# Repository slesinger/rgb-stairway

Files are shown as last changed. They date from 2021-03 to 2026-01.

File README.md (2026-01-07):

# 🌈 RGB Stairway Lighting

> Transform your staircase into a dynamic light show with motion detection and Home Assistant integration

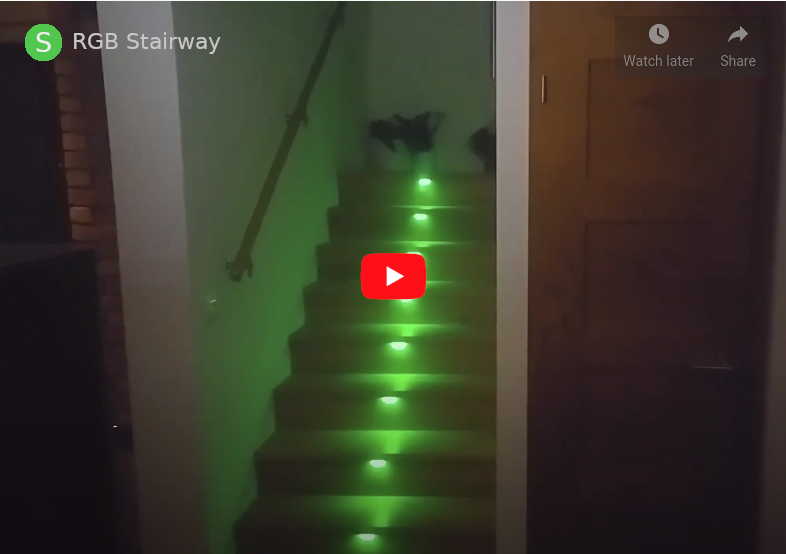
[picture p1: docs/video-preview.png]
Video Demo (https://www.youtube.com/watch?v=-Y23b8RhR6I)


## ✨ What Is This?

An ESP32-powered smart stairway lighting system that makes every trip up or down the stairs a delightful experience. Using WS2812B LED strips and IR motion detection, your stairs automatically illuminate with customizable color animations when someone approaches—then gracefully fade away. Effects can be tailored via MQTT commands from Home Assistant, allowing for endless creativity.

**Why you'll love it:**
- 🎯 Automatic detection via IR sensors (no false triggers!)
- 🎨 Per-step color control with smooth blending
- 🏠 Full Home Assistant integration via MQTT
- 🌙 Day/Night modes for smart automation
- 🎭 Custom animation programs (or use built-in random colors)
- ⚡ Real-time response using ESP32 dual-core processing
- 🔧 Easy WiFi setup with captive portal

**Creative ideas to try:**
- 🎆 National colors on holidays
- 📬 Light up N steps to show unread emails
- 🔔 Flash all stairs when someone rings the doorbell
- 🏓 Ping-pong game (race the light wave!)
- 🏃 Kids competing to beat the animation
- 🎨 Daily color themes synced with your smart home

## 🛠️ Hardware Requirements

### Components
- **ESP32** development board (e.g., Lolin32) - ESP8266 won't cut it, we need dual cores!
- **WS2812B LED strips** - 3 LEDs per step (48 LEDs total for 16 steps)
- **2× IR LED transmitters** (38kHz compatible)
- **2× IR receivers/phototransistors**
- **Quality wiring** - Use UTP cable pairs (16 wires total) for reliability
- **Power supply** - 5V, sized for your LED count

### Tested Configuration
- 16 steps total (8 bottom + 8 top)
- 3 LEDs per step
- Split into two separate strips to avoid voltage drop

> ⚠️ **Important:** Don't power more than 8 steps from one end. Split your LED strips into upper and lower sections!

## 🔌 Wiring Guide

### ESP32 Pin Assignments

| Pin | Function | Description |
|-----|---|---|
| **GPIO 13** | Bottom LED Data | WS2812B data line (steps 0-7) |
| **GPIO 12** | Top LED Data | WS2812B data line (steps 8-15) |
| **GPIO 4** | Bottom IR Receiver | IR sensor input (first step) |
| **GPIO 17** | Top IR Receiver | IR sensor input (last step) |
| **GPIO 16** | Top IR Transmitter | IR LED output (36kHz carrier) |

### Connection Notes
- Power both LED strips from adequate 5V supply
- ESP32 and LEDs should share common ground
- IR sensors work best with ~1-2 meter range across the step
- Consider resistors for IR LEDs (typically 100-330Ω depending on your LEDs)

## 🏠 Home Assistant Integration

### MQTT Topics

#### Published by Device
| Topic | Values | Description |
|---|---|---|
| `schody/sviti` | `on` / `off` | Whether any animation is currently running |
| `schody/status` | `noc` / `den` / `RECONNECTED` | Night/day mode status or reconnection event |
| `schody/ir/dole` | `on` / `off` | Bottom step IR beam broken |
| `schody/ir/nahore` | `on` / `off` | Top step IR beam broken |

#### Subscribed by Device
| Topic | Payload | Description |
|---|---|---|
| `schody/cmd` | Animation program | Custom color animation sequence |
| `schody/mode` | `N` / `D` / `R` | Night mode / Day mode / Reset |
| `schody/status` | Any | Acknowledged (resets watchdog) |

### Day/Night Modes

**Night Mode (`N`):**
- IR sensors trigger built-in animations (`PROGRAM_UPSTAIRS`/`PROGRAM_DOWNSTAIRS`)
- Instant response (~0ms delay)
- Perfect for automatic operation

**Day Mode (`D`):**
- IR sensors only publish MQTT events
- No automatic animations
- Great for manual control or disabling lights during daytime

### Sending Programs from Home Assistant

#### Simple Example (Single Step Test)
```yaml
# In your automation or script
service: mqtt.publish
data:
  topic: "schody/cmd"
  payload: "0:100(120r0g0b)1000(0r0g120b)100(0r0g0b)"
```

#### Wave Effect (All Steps)
```yaml
service: mqtt.publish
data:
  topic: "schody/cmd"
  payload: >
    0:10(0r0g0b)100(0r120g0b)8000(254r254g254b)2000(0r0g0b)
    1:50(0r0g0b)100(0r120g0b)8000(254r254g254b)2000(0r0g0b)
    2:100(0r0g0b)100(0r120g0b)8000(254r254g254b)2000(0r0g0b)
    3:150(0r0g0b)100(0r120g0b)8000(254r254g254b)2000(0r0g0b)
    ...
```

#### Random Color Animation
```yaml
service: mqtt.publish
data:
  topic: "schody/cmd"
  payload: >
    0:10(0r0g0b)100(255r255g255b)8000(254r254g254b)2000(0r0g0b)
    1:50(0r0g0b)100(255r255g255b)8000(254r254g254b)2000(0r0g0b)
    ...
```

### Program Syntax

**Format:** `<step>:<period>(<r>r<g>g<b>b)<period>(<r>r<g>g<b>b)...`

- **step:** Step number (0-15)
- **period:** Duration in **3ms ticks** (100 = 300ms)
- **r/g/b:** Color intensity (0-127 for normal values)

**Special Color Values:**
- `254` - Copy that channel from previous animation step's target (per-channel persistence)
- `255` - Random hue (generates one random color at 50% brightness)

**Examples:**
```
# Fade to red, hold, fade to black
0:10(0r0g0b)100(60r0g0b)1000(254r254g254b)2000(0r0g0b)

# Fade to red, shift to purple (R maintained, add blue)
0:10(0r0g0b)100(60r0g0b)1000(254r254g40b)2000(0r0g0b)

# Random color, hold, fade out
0:10(0r0g0b)100(255r255g255b)8000(254r254g254b)2000(0r0g0b)
```

### Home Assistant Configuration Example

```yaml
# configuration.yaml
mqtt:
  broker: YOUR_BROKER_IP
  port: 8883
  username: !secret mqtt_user
  password: !secret mqtt_password

# automations.yaml
- alias: "Stairs: Night Mode at Sunset"
  trigger:
    - platform: sun
      event: sunset
  action:
    - service: mqtt.publish
      data:
        topic: "schody/mode"
        payload: "N"

- alias: "Stairs: Day Mode at Sunrise"
  trigger:
    - platform: sun
      event: sunrise
  action:
    - service: mqtt.publish
      data:
        topic: "schody/mode"
        payload: "D"

- alias: "Stairs: Demo Animation"
  trigger:
    - platform: state
      entity_id: input_button.stairs_demo
      to: "on"
  action:
    - service: mqtt.publish
      data:
        topic: "schody/cmd"
        payload: >
          0:50(0r0g0b)60(0r120g0b)85(0b120g0r)60(0r0g0b)
          1:200(0r0g0b)60(0r120g0b)85(0b120g0r)60(0r0g0b)
          2:300(0r0g0b)60(0r120g0b)85(0b120g0r)60(0r0g0b)
          3:450(0r0g0b)60(0r120g0b)85(0b120g0r)60(0r0g0b)
```

## 📦 Installation

### Prerequisites
- [PlatformIO](https://platformio.org/) installed
- Python 3.x
- Git

### Quick Start

1. **Clone the repository**
   ```bash
   git clone https://github.com/slesinger/rgb-stairway.git
   cd rgb-stairway
   ```

2. **Create your config file**
   ```bash
   cp src/config.h-template src/config.h
   nano src/config.h  # Edit with your settings
   ```

3. **Configure settings in `src/config.h`**
   ```cpp
   #define MQTT_HOST  "192.168.1.2"      // Your MQTT broker IP
   #define MQTT_PORT  8883                // MQTT port
   #define MQTT_USER  "hass"              // MQTT username
   #define MQTT_PASS  "your_password"     // MQTT password
   
   #define WIFI_SETUP_AP_NAME "stupnice"  // Initial WiFi AP name
   #define WIFI_SETUP_AP_PASS "password123" // Initial WiFi AP password
   ```

4. **Build and upload**
   ```bash
   pio run --target upload
   ```

5. **Monitor serial output (optional)**
   ```bash
   pio device monitor
   ```

### First-Time WiFi Setup

On first boot (or when WiFi credentials are lost):

1. ESP32 creates WiFi access point named `stupnice` (or your configured name)
2. Connect to it with password `password123` (or your configured password)
3. Captive portal opens automatically (or navigate to `192.168.4.1`)
4. Select your WiFi network and enter password
5. Device reboots and connects to your network

The device will remember credentials and auto-reconnect on subsequent boots.

### Testing Your Installation

Send a test MQTT message:
```bash
mosquitto_pub -h YOUR_BROKER -p 8883 -u hass -P password \
  -t schody/cmd \
  -m "0:100(120r0g0b)1000(0r120g0b)100(0r0g0b)"
```

## 🧰 Maintenance & Updates

**Update PlatformIO packages:**
```bash
pio pkg update
```

**View serial logs:**
```bash
pio device monitor
```

**Clean build:**
```bash
pio run --target clean
pio run --target upload
```

## 📚 Libraries Used

This project leverages these excellent libraries:

- **[NeoPixelBus](https://github.com/Makuna/NeoPixelBus)** (v2.7.9+) - WS2812B LED control with DMA
- **[WiFiManager](https://github.com/tzapu/WiFiManager)** - Easy WiFi configuration
- **[PubSubClient](https://github.com/knolleary/pubsubclient)** (v2.8.0+) - MQTT client
- **[ArduinoOTA](https://github.com/esp8266/Arduino)** - Over-the-air updates (commented out by default)
- **ESP32 Arduino Core** - FreeRTOS and hardware abstraction

## 🔧 Advanced Configuration

### Customizing Default Animations

Edit `src/config.h` to modify built-in animations:

```cpp
// Random colors ascending
#define PROGRAM_UPSTAIRS "0:10(0r0g0b)100(255r255g255b)8000(254r254g254b)2000(0r0g0b) ..."

// Random colors descending
#define PROGRAM_DOWNSTAIRS "15:10(0r0g0b)100(255r255g255b)8000(254r254g254b)2000(0r0g0b) ..."

// Boot animation
#define PROGRAM_INIT "0:100(120r0g0b)100(0r120g0b)100(0r0g120b)1000(0r0g120b)100(0r0g0b)..."
```

### Adjusting Hardware Pins

Modify in `src/config.h`:
```cpp
#define NUM_SCHODU 16           // Total number of steps
#define STRIP_DOLE_PIN 13       // Bottom strip data pin
#define STRIP_NAHORE_PIN 12     // Top strip data pin
#define IR_RECV_DOLE_PIN 4      // Bottom IR receiver
#define IR_RECV_NAHORE_PIN 17   // Top IR receiver
#define IR_LED_NAHORE_PIN GPIO_NUM_16  // IR transmitter
```

## 🐛 Troubleshooting

**LEDs not lighting:**
- Check 5V power supply is adequate
- Verify data pin connections
- Ensure common ground between ESP32 and LED strips

**IR sensors not triggering:**
- Verify IR LED is powered and blinking (use phone camera to see IR)
- Check IR receiver orientation and range (1-2m optimal)
- Monitor serial output for IR debug messages

**WiFi connection issues:**
- Reset WiFi: Delete credentials and restart (access point will appear)
- Check WiFi signal strength
- Verify router supports 2.4GHz (ESP32 doesn't support 5GHz)

**MQTT not connecting:**
- Verify broker IP, port, username, password in `config.h`
- Check network connectivity: `ping YOUR_BROKER_IP`
- Monitor serial output for connection status
- Device auto-restarts if no status acknowledgment for 5 minutes

## 📄 License

This project is licensed under the MIT License - see the [LICENSE](LICENSE) file for details.

## 🙏 Contributing

Contributions are welcome! Feel free to:
- Report bugs
- Suggest new features
- Submit pull requests
- Share your stairway setup photos/videos

## ⭐ Show Your Support

If you like this project, give it a ⭐ on GitHub and share your installation on social media!

---

Made with ❤️ for makers who want their stairs to be awesome

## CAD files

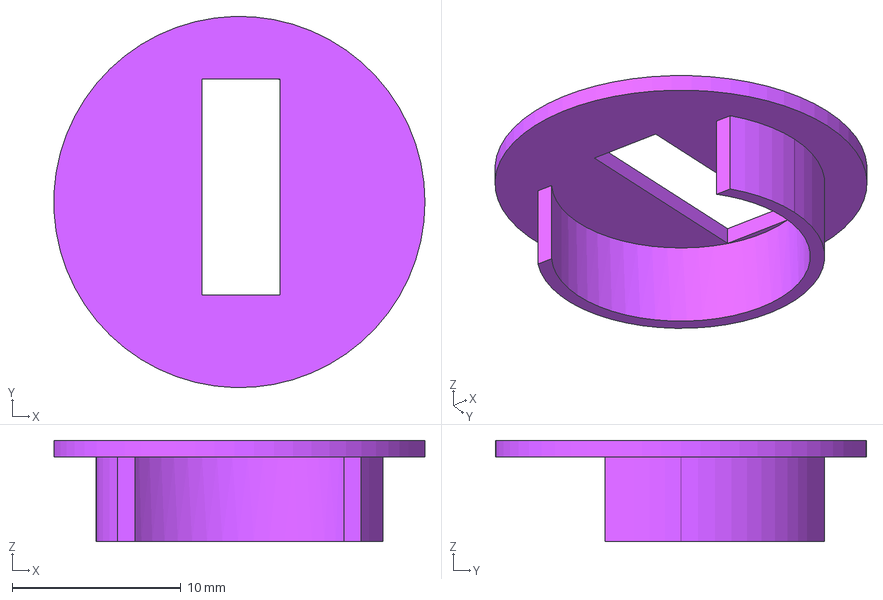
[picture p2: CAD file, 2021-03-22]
3dprint/ir-schody_v2.FCStd
22.0 x 22.0 x 6.00 mm

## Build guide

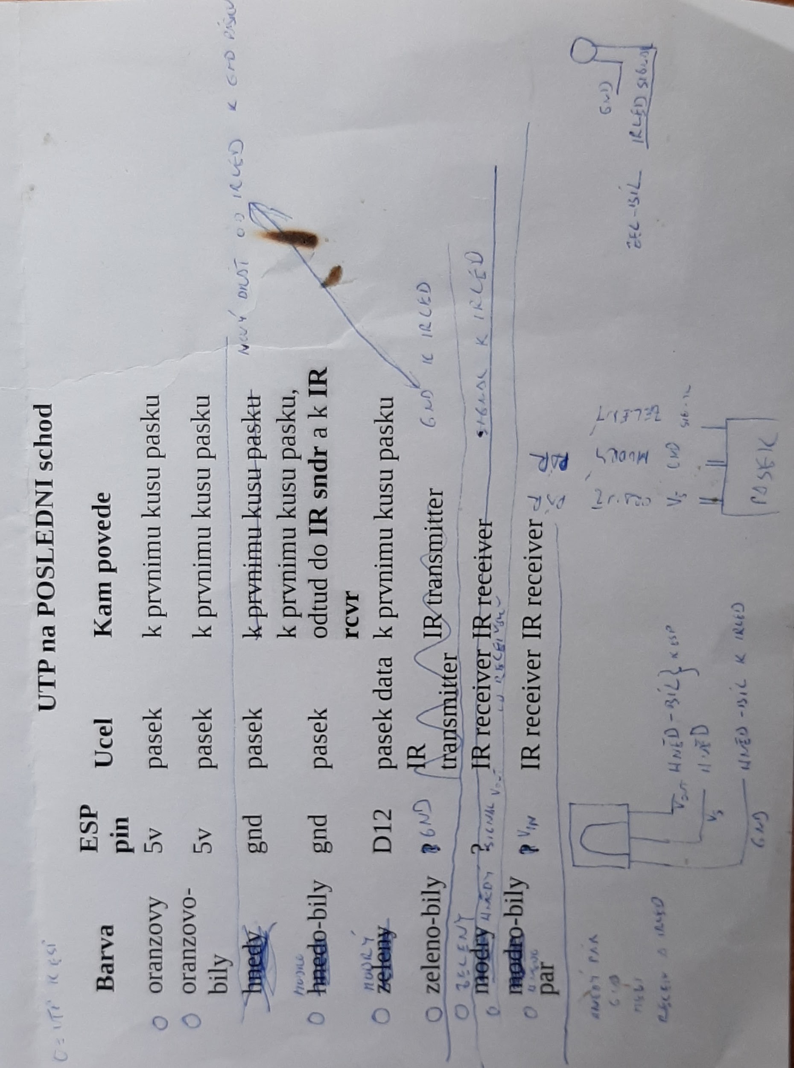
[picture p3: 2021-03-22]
docs/backup-wiring-2.jpg

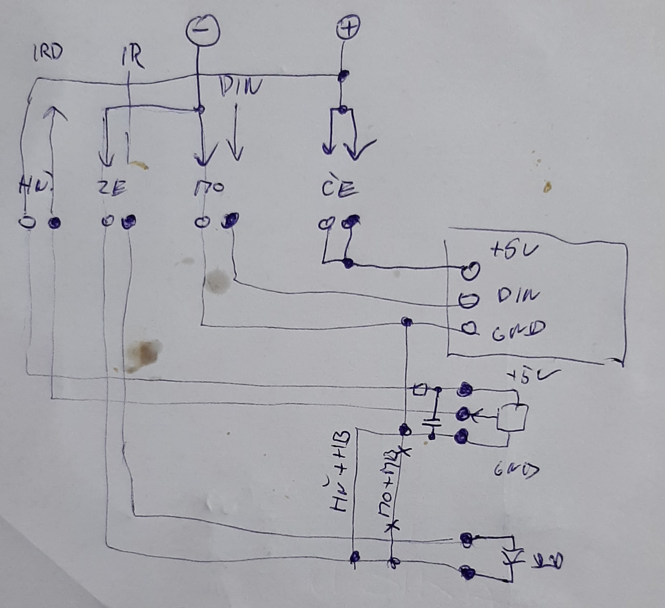
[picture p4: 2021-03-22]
docs/wiring-diagram.jpg

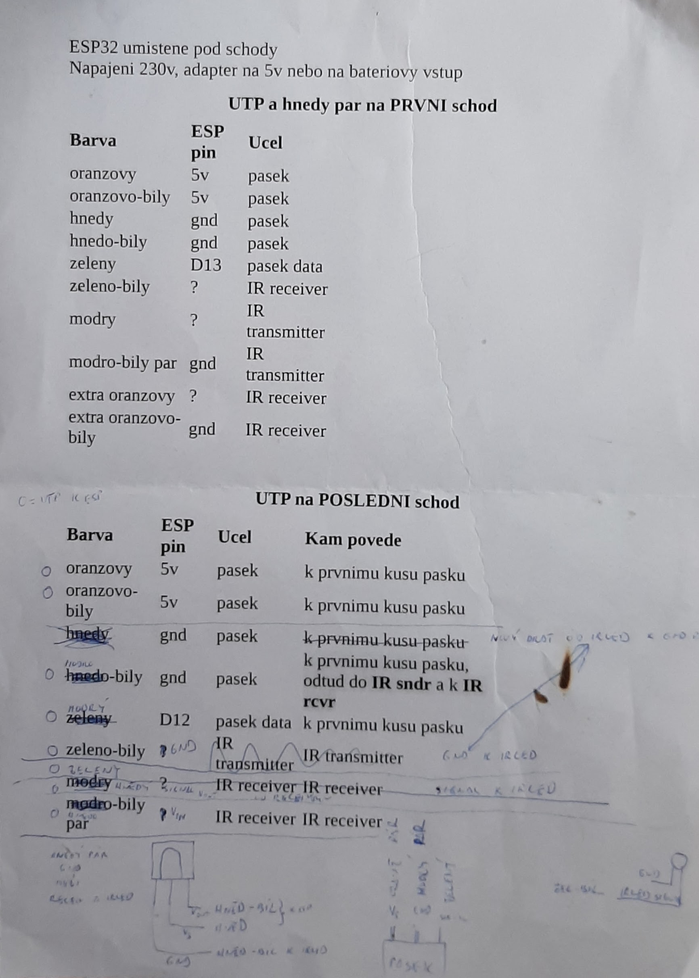
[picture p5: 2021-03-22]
docs/backup-wiring-1.jpg

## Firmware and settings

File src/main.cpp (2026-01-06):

/*
To test Schody, just publish message over MQTT:
mosquitto_pub -h localhost -p 8883 -u hass -P <mqtt password> -t schody/cmd -m <see below>

0:10(120r0g0b)1000(124R125g125B)1000(120r0g0b)1000(0r120g0b)1000(0r0g120b)1000(0r0g0b)
1:10(120r0g0b)1000(124R125g125B)1000(120g0r0b)1000(0r120b0g)1000(0b0g120r)1000(0r0g0b)

Program Syntax:
  <stair>:<period>(<r>r<g>g<b>b)<period>(<r>r<g>g<b>b)...
  
  - stair: Step number (0-15)
  - period: Duration in ticks (1 tick = 3ms)
  - r, g, b: Color values (case-insensitive)
  
  Color Value Special Cases:
    0-127: Normal color intensity
    254: Copy that specific channel from previous step's target (per-channel)
    255: Random color (single hue 0-255, saturation 100%, value 50%)
  
  Example: 0:10(0r0g0b)100(60r0g0b)1000(254r254g254b)2000(0r0g0b)
    - Fade to red, hold red for 1000 ticks (all channels copied), fade to black
  Example: 0:10(0r0g0b)100(60r0g0b)1000(254r254g40b)2000(0r0g0b)
    - Fade to red, transition to purple (R=60 copied, G=0 copied, B=40 new), fade to black

1 period = 3ms (actual execution time in task_led_strip)

Stairs are split to two part upper part (nahore) and bottom part (dole) 
*/

#include "config.h"
#include <Arduino.h>

#include <NeoPixelBus.h>

//needed for library
#include <WiFiManager.h>  //https://github.com/tzapu/WiFiManager WiFi Configuration Magic

#include <PubSubClient.h> //https://pubsubclient.knolleary.net/api.html
#include "driver/rmt.h"
#include <ArduinoOTA.h>


// builtin LED
//#define LED_BUILTIN 5
//#define DEBUG_PIN 27

#define RMT_TX_CHANNEL RMT_CHANNEL_0


bool was_falling_dole = false;
bool was_falling_nahore = false;

// which effect to display for start
RgbColor barva(10, 220, 150);
RgbColor black(0);
RgbColor c_null(0);
RgbColor red(128,0,0);
RgbColor green(0,128,0);
RgbColor blue(0,0,128);

NeoPixelBus<NeoGrbFeature, NeoEsp32I2s0800KbpsMethod> strip_dole(NUM_SCHODU/2*3, STRIP_DOLE_PIN);
NeoPixelBus<NeoGrbFeature, NeoEsp32I2s1800KbpsMethod> strip_nahore(NUM_SCHODU/2*3, STRIP_NAHORE_PIN);

WiFiManager wifiManager;
WiFiClient espClient;
PubSubClient client(espClient);

boolean irdole_publish = false;
boolean irnahore_publish = false;
boolean ma_se_poslat_konec_sviceni = true;
boolean is_night_enabled = true;
long lastStatusAck = 0;

void setSchod(int id, RgbColor moje_barva)
{
  // moje_barva.Darken(255 - intenzita);
  if (id <= 7) {
    int i = id * 3;
    strip_dole.SetPixelColor(i, moje_barva);
    strip_dole.SetPixelColor(i+1, moje_barva);
    strip_dole.SetPixelColor(i+2, moje_barva);
  }
  else {
    int i = (15 - id) * 3;
    strip_nahore.SetPixelColor(i, moje_barva);
    strip_nahore.SetPixelColor(i+1, moje_barva);
    strip_nahore.SetPixelColor(i+2, moje_barva);
  }
}

void showSchody(){
  strip_dole.Show();
  strip_nahore.Show();
}

/* #Program
   for each stair-step
    commands:
      - //set_color (period, color) - same as blend(0, color)
      - blend (period, color) - as this is only command, does not need to specify in program, is implicit
    command parameter
      - period uint_16
      - target color
*/
struct RgbColorFloat {
  float R;
  float G;
  float B;
  float deltaR;
  float deltaG;
  float deltaB;
};
struct Program_step {
  uint16_t period;
  RgbColor target_color;
};
Program_step program[NUM_SCHODU][NUM_PROG_STEPS];
unsigned int program_pointers[NUM_SCHODU];
RgbColorFloat program_current_color[NUM_SCHODU];

void program_clear() {}

void program_load(byte* prg, unsigned int length) {
    // char prg[] = "0:1200(124R125g127B)0(0R0g0b)\n1:1201(121R121g121B)1(1R1g1b)";
    
    //init zero values
    for (int schod = 0; schod < NUM_SCHODU; schod++) {
      program_pointers[schod] = NUM_PROG_STEPS;   // pause execution
      program_current_color[schod] = {.R = 0, .G = 0, .B = 0, .deltaR = 0, .deltaG = 0, .deltaB = 0};

      for (int step = 0; step < NUM_PROG_STEPS; step++) {
        program[schod][step] = { .period = LAST_PROG_STEP, .target_color = black};
      }
    }

    //load from string
    unsigned int num = 0;
    unsigned int schod = 0;
    unsigned int step = 0;
    uint16_t period = 0;
    unsigned int r = 0;
    unsigned int g = 0;
    unsigned int b = 0;
    unsigned char* curr_prg = prg;
    for (unsigned int i = 0; i < length; i++) {
        unsigned char ch = *curr_prg;
        
        if (ch >= '0' && ch <= '9') {
            num = num*10 + ch-48;
        }
        if (ch == ':') {
            if (schod != num) step = 0;
            schod = num;
            num = 0;
        }
        if (ch == '(') {
            period = num;
            num = 0;
        }
        if (ch == 'R' || ch == 'r') {
            r = num;
            num = 0;
        }
        if (ch == 'G' || ch == 'g') {
            g = num;
            num = 0;
        }
        if (ch == 'B' || ch == 'b') {
            b = num;
            num = 0;
        }
        if (ch == ')') {
          if (schod < NUM_SCHODU && step < NUM_PROG_STEPS) {
            // Store values as-is, handling special values later
            uint16_t rr = (r >= 254) ? r : (r % 127);
            uint16_t gg = (g >= 254) ? g : (g % 127);
            uint16_t bb = (b >= 254) ? b : (b % 127);
            
            // Handle 254 per-channel: copy that specific channel from previous step's target
            if (step > 0) {
              RgbColor prev_target = program[schod][step - 1].target_color;
              if (rr == 254) rr = prev_target.R;
              if (gg == 254) gg = prev_target.G;
              if (bb == 254) bb = prev_target.B;
            } else {
              // For first step, if 254 is used, default to 0 for that channel
              if (rr == 254) rr = 0;
              if (gg == 254) gg = 0;
              if (bb == 254) bb = 0;
            }
            
            // Handle 255: generate random color using HSV
            // Generate single random hue (0-255), S=100%, V=50%
            if (rr == 255 || gg == 255 || bb == 255) {
              uint32_t random_val = esp_random();
              uint8_t hue = (random_val & 0xFF);  // Random hue 0-255
              
              // Create HSB color: Hue (0-360 mapped from 0-255), Saturation 100%, Brightness 50%
              // NeoPixelBus uses float values: H=0.0-1.0, S=0.0-1.0, B=0.0-1.0
              HsbColor hsb_color(hue / 255.0f, 1.0f, 0.5f);
              RgbColor rgb_color(hsb_color);
              
              // Only apply to channels that were set to 255
              if (rr == 255) rr = rgb_color.R;
              if (gg == 255) gg = rgb_color.G;
              if (bb == 255) bb = rgb_color.B;
            }
            
            program[schod][step] = { .period = period, .target_color = RgbColor(rr, gg, bb) };
            step++;
          } else {
            Serial.printf("Warning: Ignoring program step schod=%u, step=%u (out of bounds)\n", schod, step);
          }
        }
        curr_prg++;
    }

    for (int schod = 0; schod < NUM_SCHODU; schod++) {
      RgbColor targ_col = program[schod][0].target_color;
      // 254 values have already been resolved during parsing, so just use target as-is
      program_current_color[schod].deltaR = ((float)targ_col.R - 0) / (float)program[schod][0].period;
      program_current_color[schod].deltaG = ((float)targ_col.G - 0) / (float)program[schod][0].period;
      program_current_color[schod].deltaB = ((float)targ_col.B - 0) / (float)program[schod][0].period;
      program_pointers[schod] = 0;   // exceutes from 0 to NUM_PROG_STEPS
    }

  client.publish("schody/sviti", "on", true);
  ma_se_poslat_konec_sviceni = true;

}

void task_led_strip(void *parameter) {
  while (true) {

    //Execute program for each stair
    for (int schod = 0; schod < NUM_SCHODU; schod++) {

      if (program_pointers[schod] == NUM_PROG_STEPS) {
        continue; //program executed completely, skip this stair
      }

      if (program[schod][program_pointers[schod]].period == 0) {
        program_pointers[schod]++; //period for given step passed, go to next program step
        //calculate blending deltas (254 values already resolved during load)
        RgbColor targ_col = program[schod][program_pointers[schod]].target_color;
        program_current_color[schod].deltaR = ((float)targ_col.R - program_current_color[schod].R) / (float)program[schod][program_pointers[schod]].period;
        program_current_color[schod].deltaG = ((float)targ_col.G - program_current_color[schod].G) / (float)program[schod][program_pointers[schod]].period;
        program_current_color[schod].deltaB = ((float)targ_col.B - program_current_color[schod].B) / (float)program[schod][program_pointers[schod]].period;
      }
      else if (program[schod][program_pointers[schod]].period == LAST_PROG_STEP) { // period indicates end of program
        program_pointers[schod] = NUM_PROG_STEPS; //set pointer as last step
        if (ma_se_poslat_konec_sviceni == true) {
          ma_se_poslat_konec_sviceni = false;
          client.publish("schody/sviti", "off", true);
        }     
        continue;
      }
      else {
        program[schod][program_pointers[schod]].period--;
        program_current_color[schod].R += program_current_color[schod].deltaR;
        program_current_color[schod].G += program_current_color[schod].deltaG;
        program_current_color[schod].B += program_current_color[schod].deltaB;
        // All special values (254, 255) already resolved during program load
        uint8_t r = (uint8_t)program_current_color[schod].R;
        uint8_t g = (uint8_t)program_current_color[schod].G;
        uint8_t b = (uint8_t)program_current_color[schod].B;
        RgbColor new_col(r, g, b);
        setSchod(schod, new_col); //TODO vylepsit setSchod API - odebrat intensity
      }
    }
    showSchody();
    vTaskDelay( 3 / portTICK_PERIOD_MS);
  }
}

void task_ota_handle(void *parameter) {
  while (true) {
    ArduinoOTA.handle();
    vTaskDelay(10 / portTICK_PERIOD_MS);
  }
}


void setup_wifi()
{
  // wifiManager.setCountry("CZ");
  wifiManager.autoConnect(WIFI_SETUP_AP_NAME, WIFI_SETUP_AP_PASS); //AP of this ESP device for initial config
  // wifiManager.setWiFiAutoReconnect(true);
  Serial.print("IP address: ");                        //kdyz se pripoji na stromecek
  Serial.println(WiFi.localIP());
}

struct Button
{
  const uint8_t PIN;
  uint32_t numberKeyPresses;
  bool pressed;
};
Button ir_rcvr_dole = {IR_RECV_DOLE_PIN, 0, false};
Button ir_rcvr_nahore = {IR_RECV_NAHORE_PIN, 0, false};
//Button debug_button = {15, 0, false};

//void IRAM_ATTR isr_debug()
//{
//  digitalWrite(DEBUG_PIN, LOW);
//}

void IRAM_ATTR isr_dole()
{
  was_falling_dole = true;
}
void IRAM_ATTR isr_nahore()
{
  was_falling_nahore = true;
}

void setup_ir() {

  //setup transmitter LED
  rmt_config_t config;
  config.rmt_mode = RMT_MODE_TX;
  config.channel = RMT_TX_CHANNEL;
  config.gpio_num = IR_LED_NAHORE_PIN;
  config.mem_block_num = 1;
  config.tx_config.loop_en = 0;
  config.tx_config.carrier_en = 1;
  config.tx_config.idle_output_en = 0;
  config.tx_config.idle_level = RMT_IDLE_LEVEL_LOW;
  config.tx_config.carrier_duty_percent = 50;
  config.tx_config.carrier_freq_hz = 36000;
  config.tx_config.carrier_level = RMT_CARRIER_LEVEL_HIGH;
  config.clk_div = 255; //maximum resolution

  ESP_ERROR_CHECK(rmt_config(&config));
  ESP_ERROR_CHECK(rmt_driver_install(config.channel, 0, 0));

  // setup receiver
  pinMode(ir_rcvr_dole.PIN, INPUT_PULLUP);
  attachInterrupt(ir_rcvr_dole.PIN, isr_dole, FALLING);

  pinMode(ir_rcvr_nahore.PIN, INPUT_PULLUP);
  attachInterrupt(ir_rcvr_nahore.PIN, isr_nahore, FALLING);
}

rmt_item32_t rmt_items[] = {
    {{{ 150, 1, 300, 0 }}}, // dot
};

#define TICKS_GUARDED_PERIOD 5000
#define TICKS_VALIDATION_PERIOD 50
#define TICKS_BLOCKED 45 //minimum ticks with blocked IR during validation period

void task_tx_ir(void *parameter)
{
  unsigned int ticks = 0;
  unsigned int ticks_guarded = 0;
  unsigned int countdown_publish_dole = 0;
  unsigned int countdown_publish_nahore = 0;
  while (true) {
    int number_of_items = sizeof(rmt_items) / sizeof(rmt_items[0]);
    rmt_write_items(RMT_TX_CHANNEL, rmt_items, number_of_items, true);
    vTaskDelay( 1 / portTICK_PERIOD_MS / 2);  //[ms]  500us

    if (ticks_guarded > 0) {  //Do not register IR blocking after mqtt IR block published
      ticks_guarded--;
    }
    else {
      if (ticks > 0) ticks--;

      if (ticks == 0 && countdown_publish_dole > TICKS_BLOCKED) {
        irdole_publish = true;
        countdown_publish_dole = 0;
        ticks_guarded = TICKS_GUARDED_PERIOD;
      }
      if (ticks == 0 && countdown_publish_nahore > TICKS_BLOCKED) {
        irnahore_publish = true;
        countdown_publish_nahore = 0;
        ticks_guarded = TICKS_GUARDED_PERIOD;
      }

      if ( (was_falling_dole != true) && (digitalRead(ir_rcvr_dole.PIN)) ) {
        if (ticks == 0) { // ticks count down needs to start
          ticks = TICKS_VALIDATION_PERIOD;
          countdown_publish_dole = 0;
        }
        countdown_publish_dole++;  // count ticks during IR bocked
      }
      was_falling_dole = false;

      if ( (was_falling_nahore != true) && (digitalRead(ir_rcvr_nahore.PIN)) ) {
        if (ticks == 0) {
          ticks = TICKS_VALIDATION_PERIOD;
          countdown_publish_nahore = 0;
        }
        countdown_publish_nahore++;
      }
      was_falling_nahore = false;
    }
    vTaskDelay( 3 / portTICK_PERIOD_MS);  //[ms]  3ms
  }
}

void mqtt_handler(const char* topic, byte* payload, unsigned int length) {
  Serial.println(topic);
  if (strcmp(topic, "schody/cmd") == 0) {
    program_load(payload, length);
  }
  else if (strcmp(topic, "schody/mode") == 0) {
    if (payload[0] == 'N') is_night_enabled = true;
    else if (payload[0] == 'D') is_night_enabled = false;
    else if (payload[0] == 'R') ESP.restart();
  }
  else if (strcmp(topic, "schody/status") == 0) {
    lastStatusAck = millis();
  }
}

void mqtt_reconnect()
{
  if (!client.connected())
  {
    Serial.printf("MQTT connection state %d. Trying to connect...", client.state());

    // if (client.connect(MQTT_TOPIC, MQTT_USER, MQTT_PASS), true)
    if (client.connect(MQTT_TOPIC, MQTT_USER, MQTT_PASS, nullptr, 0, false, nullptr, true))
    {
      Serial.println("connected");
      client.setBufferSize(4096); //to fit long program sent to schody/cmd
      client.setCallback(&mqtt_handler);
      client.subscribe("schody/cmd", 0);
      client.subscribe("schody/mode", 0);
      client.subscribe("schody/status", 0);
    }
    else
    {
      Serial.print("failed, rc=");
      Serial.print(client.state());
      Serial.println(" try again in 5 seconds");
    }
  }
}
void setup_mqtt()
{
  client.setServer(MQTT_HOST, MQTT_PORT);
  mqtt_reconnect();
}

void task_mqtt_status_publish(void *parameter) {
  while (true) {
    if (!client.connected()) {
      mqtt_reconnect();
      client.publish("schody/status", String("RECONNECTED").c_str(), true);
    }
    // Send 'noc' if enabled (night), 'den' if disabled (day)
    if (is_night_enabled) {
      client.publish("schody/status", "noc", true);
    } else {
      client.publish("schody/status", "den", true);
    }

    if (millis() - lastStatusAck > 300000) {  // reset every 5 minutes if status not acknowledged
      Serial.print("Going to restart due to no status ack for 5 minutes. Last ack before[ms]: ");
      Serial.println(millis() - lastStatusAck);
      esp_restart();
    }
    vTaskDelay( 10000 / portTICK_PERIOD_MS);
  }
}

void task_mqtt_ir_publish(void *parameter) {
  while (true) {
    if (irdole_publish) {
      if (is_night_enabled) program_load((byte*)PROGRAM_UPSTAIRS, strlen(PROGRAM_UPSTAIRS));
      client.publish("schody/ir/dole", "on", true);
      irdole_publish = false;
      client.loop();
      vTaskDelay( 1000 / portTICK_PERIOD_MS);
      client.publish("schody/ir/dole", "off", true);
    }
    if (irnahore_publish) {
      if (is_night_enabled) program_load((byte*)PROGRAM_DOWNSTAIRS, strlen(PROGRAM_DOWNSTAIRS));
      client.publish("schody/ir/nahore", "on", true);
      irnahore_publish = false;
      client.loop();
      vTaskDelay( 1000 / portTICK_PERIOD_MS);
      client.publish("schody/ir/nahore", "off", true);
    }
    client.loop();
    vTaskDelay( 500 / portTICK_PERIOD_MS);
  }
}


void setup() {
  // sanity check delay - allows reprogramming if accidently blowing power w/leds
  delay(2000);
  lastStatusAck = millis();
  Serial.begin(9600);
  
  // Seed standard random generator (ESP32 auto-seeds from hardware noise)
  randomSeed(analogRead(0) + millis());
  
  strip_dole.Begin();
  strip_nahore.Begin();
  program_load((byte*)PROGRAM_INIT, strlen(PROGRAM_INIT));
  showSchody();
  setup_ir();
  setup_wifi();
  delay(1000);
  setup_mqtt();
  //pinMode(DEBUG_PIN, OUTPUT);
  //pinMode(LED_BUILTIN, OUTPUT);
  //digitalWrite(DEBUG_PIN, LOW);

  //pinMode(debug_button.PIN, INPUT_PULLUP);
  //attachInterrupt(debug_button.PIN, isr_debug, FALLING);


  /*
  &taskLedStrip,     Task function.
  "TaskLedStrip",    String with name of task.
  10000,             Stack size in words.
  NULL,              Parameter passed as input of the task
  1,                 Priority of the task. Higher number high prio up to 32
  NULL);             Task handle. */
  xTaskCreate(&task_led_strip, "TaskLedStrip", 10000, NULL, 16, NULL);
  xTaskCreate(&task_tx_ir, "TaskTxIr", 10000, NULL, 2, NULL);
  xTaskCreate(&task_mqtt_status_publish, "TaskMqttPublish", 10000, NULL, 1, NULL);
  xTaskCreate(&task_mqtt_ir_publish, "TaskMqttPublish", 10000, NULL, 1, NULL);

  // OTA setup
  // ArduinoOTA.setHostname("schody-esp32");
  // ArduinoOTA.onStart([]() {
  //   Serial.println("OTA Update Start");
  // });
  // ArduinoOTA.onEnd([]() {
  //   Serial.println("OTA Update End");
  // });
  // ArduinoOTA.onError([](ota_error_t error) {
  //   Serial.printf("OTA Error[%u]: ", error);
  //   if (error == OTA_AUTH_ERROR) Serial.println("Auth Failed");
  //   else if (error == OTA_BEGIN_ERROR) Serial.println("Begin Failed");
  //   else if (error == OTA_CONNECT_ERROR) Serial.println("Connect Failed");
  //   else if (error == OTA_RECEIVE_ERROR) Serial.println("Receive Failed");
  //   else if (error == OTA_END_ERROR) Serial.println("End Failed");
  // });
  // ArduinoOTA.begin();
  // xTaskCreate(&task_ota_handle, "TaskOtaHandle", 10000, NULL, 1, NULL);
}

void loop()
{
  delay(1000);
}

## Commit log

2021-04-26 just trying
    See: https://github.com/tzapu/WiFiManager/issues/532
    [main.cpp]
2022-10-15 tzapu wifimanager, fixed dependencies
    [main.cpp]
